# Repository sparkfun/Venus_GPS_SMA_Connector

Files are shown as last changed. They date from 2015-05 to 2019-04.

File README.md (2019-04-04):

**NOTE:** *This product has been retired from our catalog. If you are looking for more up-to-date info, please check out some of these resources to see how other users are still hacking and improving on this product.*
* *[SparkFun Forum](https://forum.sparkfun.com/)*
* *[Comments Here on GitHub](https://github.com/sparkfun/Venus_GPS_SMA_Connector/issues)*
* *[IRC Channel](https://www.sparkfun.com/news/263)*

SparkFun Venus GPS with SMA Connector
========================================

SparkFun Venus GPS with SMA Connector

[*SparkFun Venus GPS with SMA Connector (GPS-11058)*](https://www.sparkfun.com/products/11058)

This is the latest version of our Venus GPS board; the smallest, most powerful, and most versatile GPS receiver we carry. It’s based on the Venus638FLPx, the successor to the Venus634LPx. 
The Venus638FLPx outputs standard NMEA-0183 or SkyTraq Binary sentences at a default rate of 9600bps (adjustable to 115200bps), with update rates up to 20Hz! 
The Venus638FLPx also allows for limited on-chip logging (check out the firmware below), as well as external logging using a SPI flash memory chip (not included).

Repository Contents
-------------------

* **/Hardware** - Eagle design files (.brd, .sch)
* **/Production** - Production panel files (.brd)

Documentation
--------------

* **[SparkFun Fritzing repo](https://github.com/sparkfun/Fritzing_Parts)** - Fritzing diagrams for SparkFun products.
* **[SparkFun 3D Model repo](https://github.com/sparkfun/3D_Models)** - 3D models of SparkFun products. 

License Information
-------------------
This product is _**open source**_! 

The **hardware** is released under [Creative Commons ShareAlike 4.0 International](https://creativecommons.org/licenses/by-sa/4.0/).

Please use, reuse, and modify these files as you see fit. Please maintain attribution to SparkFun Electronics and release anything derivative under the same license.

Distributed as-is; no warranty is given.

- Your friends at SparkFun.

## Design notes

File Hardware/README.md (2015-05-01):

SparkFun <PRODUCT NAME> Design Files
=====================================

The .sch and .brd files hare are Eagle CAD schematic and PCB design files from SparkFun Electronics.
A freeware version of Eagle can be found [here](http://www.cadsoftusa.com/download-eagle/freeware/). 

License
---------
This product is open source! 
The hardware is released under [Creative Commons ShareAlike 4.0 International](https://creativecommons.org/licenses/by-sa/4.0/).

Please use, reuse, and modify these files as you see fit. Please maintain attribution to SparkFun Electronics and release anything derivative under the same license.

Distributed as-is; no warranty is given.

- Your friends at SparkFun.

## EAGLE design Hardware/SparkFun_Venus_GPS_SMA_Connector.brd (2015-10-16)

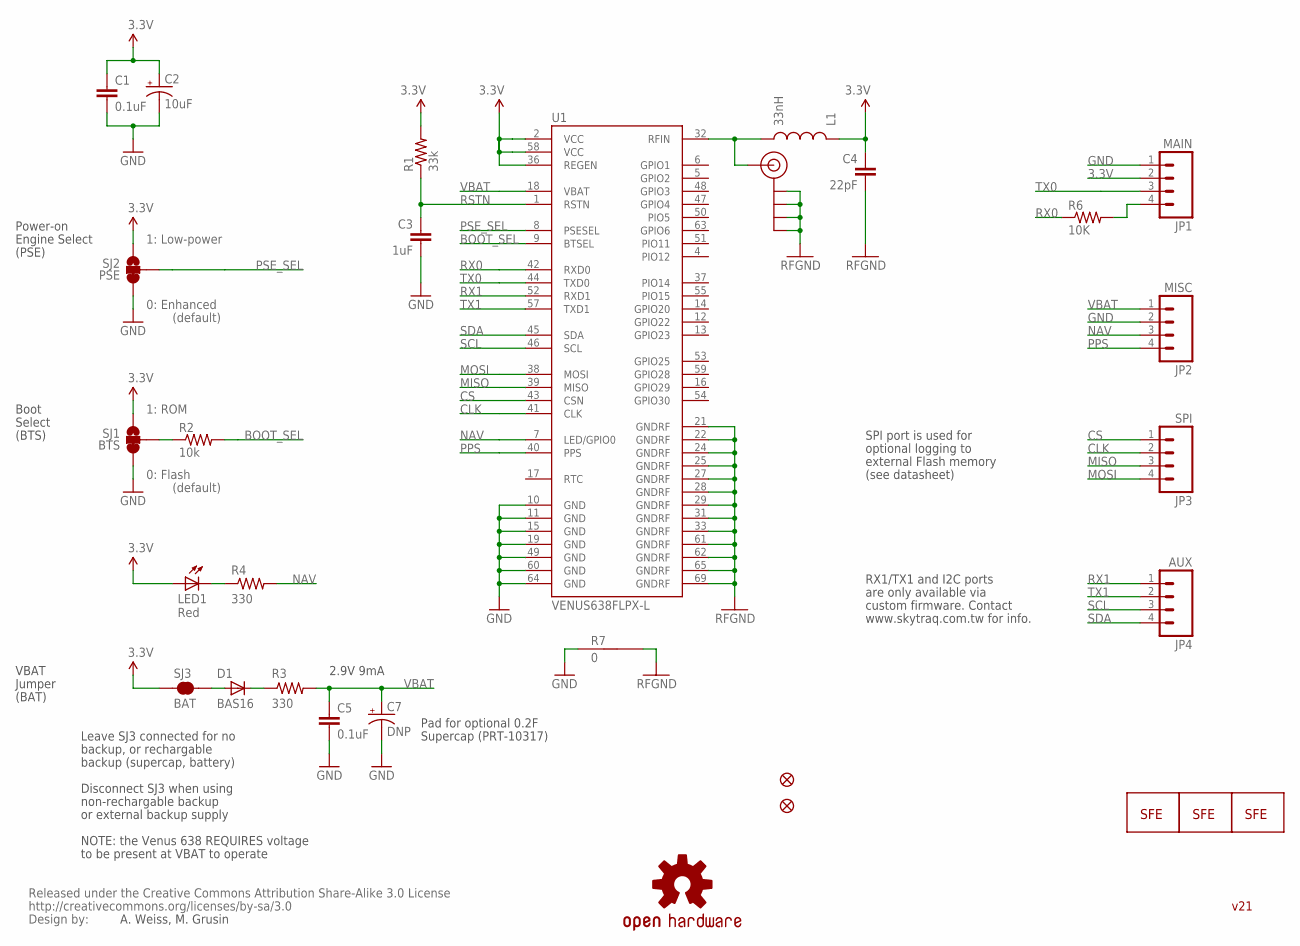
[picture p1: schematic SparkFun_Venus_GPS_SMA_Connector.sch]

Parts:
C1, C5: 0.1uF; 0402-CAP
C2: 10uF; EIA3216
C3: 1uF; 0402-CAP
C4: 22pF; 0402-CAP
C7: DNP; EN_J2
D1: BAS16; SOD-323
JP1: MAIN; 1X04
JP2: MISC; 1X04
JP3: SPI; 1X04
JP4: AUX; 1X04
JP5: SMA_EDGE; SMA-EDGE
JP6, JP7: FIDUCIALUFIDUCIAL; MICRO-FIDUCIAL
L1: 33nH; C0402
LED1: Red; LED-0603
LOGO1, LOGO2: LOGO-SFESK; SFE-LOGO-FLAME
LOGO3: LOGO-SFENW2; SFE-NEW-WEB
R1: 33k; 0402-RES
R2: 10k; 0402-RES
R3, R4: 330; 0402-RES
R6: 10K; 0402-RES
R7: 0; GND-JUMP
SJ1: BTS; SJ_3_PASTE2&3
SJ2: PSE; SJ_3_PASTE2&3
SJ3: BAT; SJ_2S
U1: VENUS638FLPX-L; VENUS638FLPX
U$4: OSHW-LOGOS; OSHW-LOGO-S
U$5: CREATIVE_COMMONS

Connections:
3.3V: C1.1, C2.A (+), C4.1, JP1.2, L1.1, LED1.A, R1.2, SJ1.1, SJ2.1, SJ3.1, U1.2 (VCC), U1.36 (REGEN), U1.58 (VCC)
ANT: JP5.SIG (SIGNAL), L1.2, U1.32 (RFIN)
BOOT_SEL: R2.2, U1.9 (BTSEL)
CLK: JP3.2, U1.41 (CLK)
CS: JP3.1, U1.43 (CSN)
GND: C1.2, C2.C (-), C3.2, C5.2, C7.-, JP1.1, JP2.2, R7.1, SJ1.3, SJ2.3, U1.10 (GND), U1.11 (GND), U1.15 (GND), U1.19 (GND), U1.49 (GND), U1.60 (GND), U1.64 (GND)
MISO: JP3.3, U1.39 (MISO)
MOSI: JP3.4, U1.38 (MOSI)
unnamed: LED1.C, R4.1
unnamed: R2.1, SJ1.2
unnamed: D1.1 (C), R3.1
unnamed: D1.2 (A), SJ3.2
NAV: JP2.3, R4.2, U1.7 (LED/GPIO0)
PPS: JP2.4, U1.40 (PPS)
PSE_SEL: SJ2.2, U1.8 (PSESEL)
RFGND: C4.2, JP5.GND@0 (GND), JP5.GND@1 (GND), JP5.GND@2 (GND), JP5.GND@3 (GND), R7.2, U1.21 (GNDRF), U1.22 (GNDRF), U1.24 (GNDRF), U1.25 (GNDRF), U1.27 (GNDRF), U1.28 (GNDRF), U1.29 (GNDRF), U1.31 (GNDRF), U1.33 (GNDRF), U1.61 (GNDRF), U1.62 (GNDRF), U1.65 (GNDRF), U1.69 (GNDRF)
RSTN: C3.1, R1.1, U1.1 (RSTN)
RX0: R6.1, U1.42 (RXD0)
RX1: JP4.1, U1.52 (RXD1)
RX01: JP1.4, R6.2
SCL: JP4.3, U1.46 (SCL)
SDA: JP4.4, U1.45 (SDA)
TX0: JP1.3, U1.44 (TXD0)
TX1: JP4.2, U1.57 (TXD1)
VBAT: C5.1, C7.+, JP2.1, R3.2, U1.18 (VBAT)

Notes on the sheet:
RFGND
1: Low-power
0: Enhanced
0: Flash
1: ROM
(default)
A. Weiss, M. Grusin
Supercap (PRT-10317)
Pad for optional 0.2F
2.9V 9mA
RX1/TX1 and I2C ports
are only available via
SPI port is used for
optional logging to
external Flash memory
(see datasheet)
custom firmware. Contact
www.skytraq.com.tw for info.
Power-on
Engine Select
Boot
Select
(PSE)
(BTS)
VBAT
Jumper
(BAT)
Leave SJ3 connected for no
backup, or rechargable
backup (supercap, battery)
Disconnect SJ3 when using
non-rechargable backup
or external backup supply
NOTE: the Venus 638 REQUIRES voltage
to be present at VBAT to operate
v21

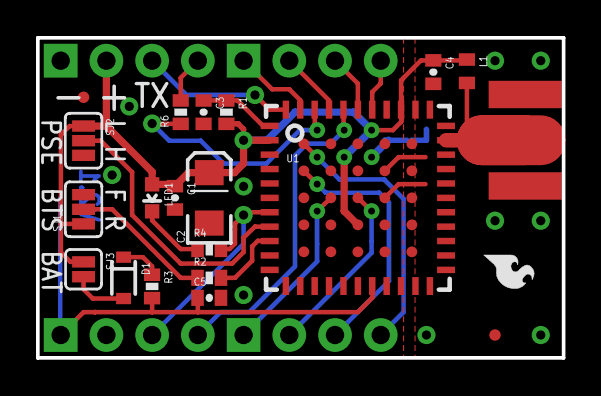
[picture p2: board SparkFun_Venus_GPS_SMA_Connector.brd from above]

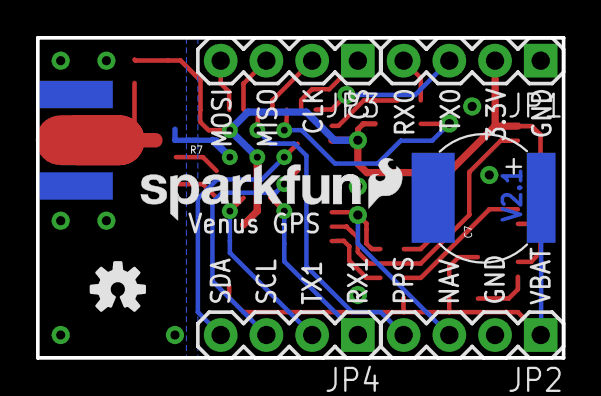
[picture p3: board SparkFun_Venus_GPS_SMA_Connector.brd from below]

Board: 2 copper layers, 29.2 x 17.8 mm, 31 parts (9 on the bottom side), 25 nets.

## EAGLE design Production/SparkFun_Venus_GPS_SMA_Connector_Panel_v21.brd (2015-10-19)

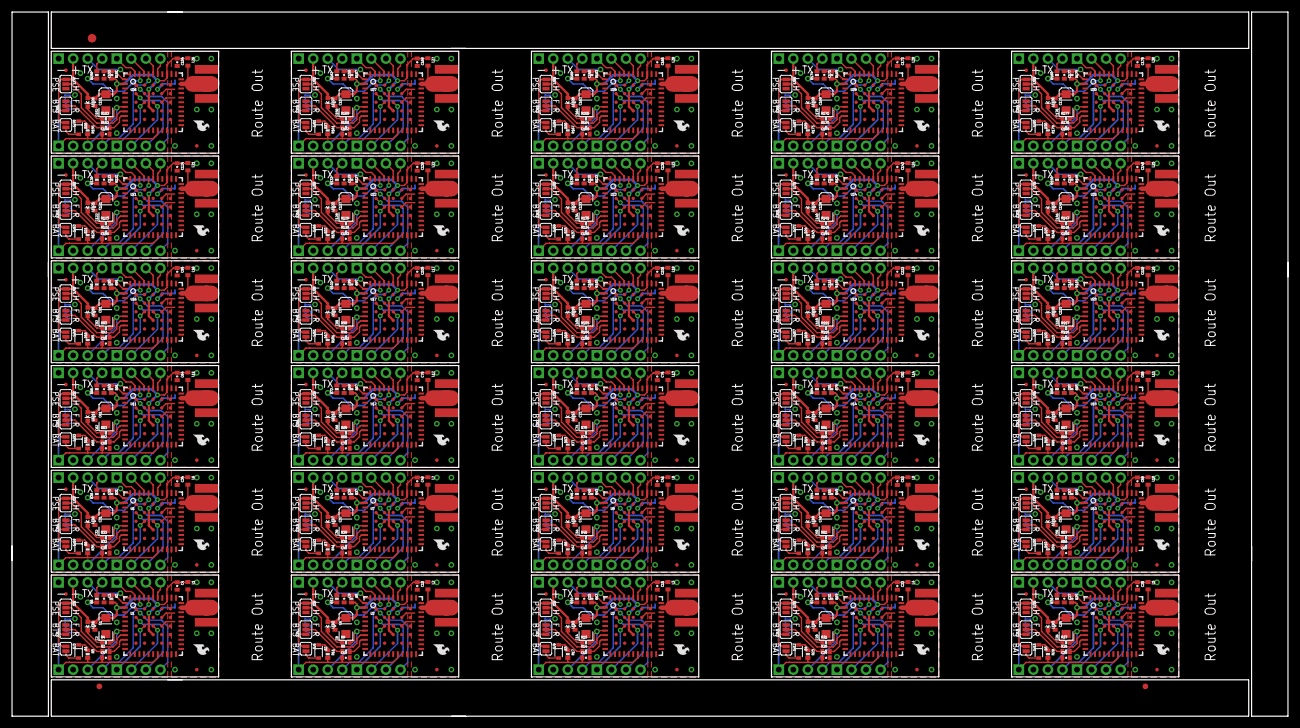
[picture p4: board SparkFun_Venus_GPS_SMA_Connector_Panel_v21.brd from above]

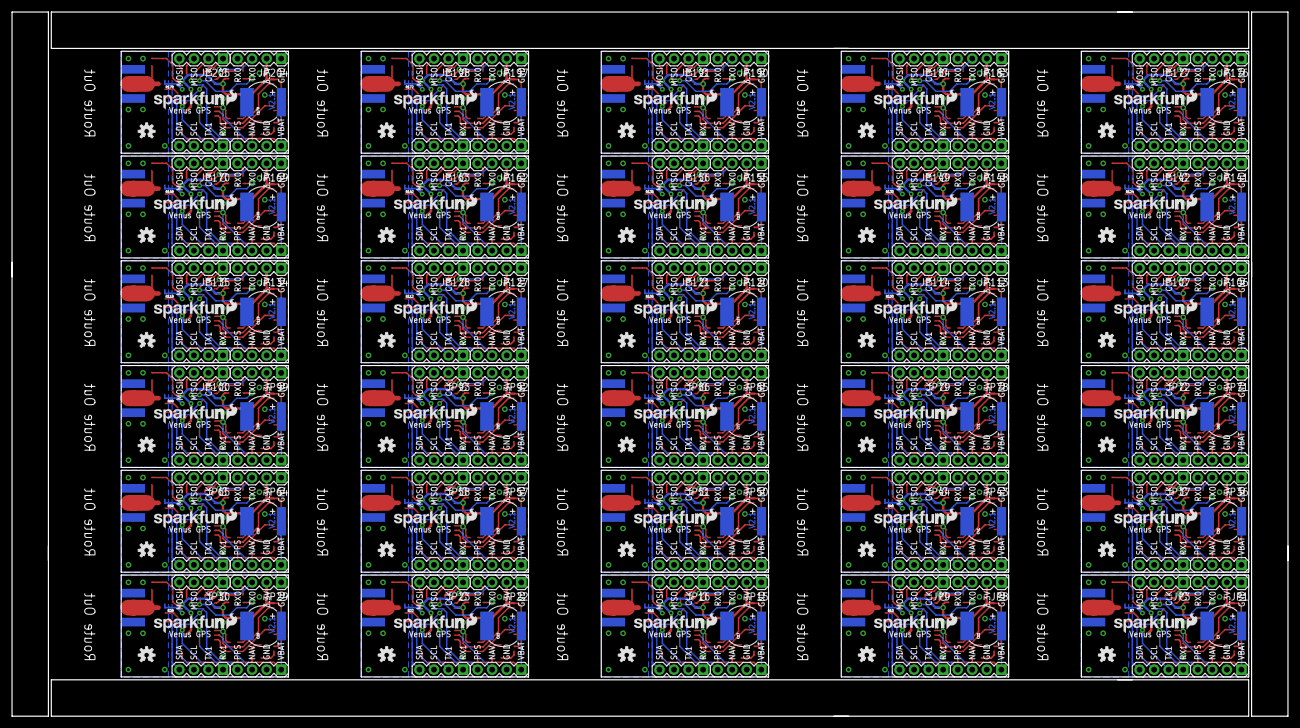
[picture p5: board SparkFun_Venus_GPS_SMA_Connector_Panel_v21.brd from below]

Board: 2 copper layers, 222.8 x 122.9 mm, 903 parts (270 on the bottom side), 750 nets.

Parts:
C1, C5, C6, C12, C13, C18, C19, C24, C25, C30, C31, C36, C37, C42, C43, C48, C49, C54, C55, C60, C61, C66, C67, C72, C73, C78, C79, C84, C85, C90, C91, C96, C97, C102, C103, C108, C109, C114, C115, C120, C121, C126, C127, C132, C133, C138, C139, C144, C145, C150, C151, C156, C157, C162, C163, C168, C169, C174, C175, C180: 0.1uF; 0402-CAP
C2, C8, C14, C20, C26, C32, C38, C44, C50, C56, C62, C68, C74, C80, C86, C92, C98, C104, C110, C116, C122, C128, C134, C140, C146, C152, C158, C164, C170, C176: 10uF; EIA3216
C3, C9, C15, C21, C27, C33, C39, C45, C51, C57, C63, C69, C75, C81, C87, C93, C99, C105, C111, C117, C123, C129, C135, C141, C147, C153, C159, C165, C171, C177: 1uF; 0402-CAP
C4, C10, C16, C22, C28, C34, C40, C46, C52, C58, C64, C70, C76, C82, C88, C94, C100, C106, C112, C118, C124, C130, C136, C142, C148, C154, C160, C166, C172, C178: 22pF; 0402-CAP
C7, C11, C17, C23, C29, C35, C41, C47, C53, C59, C65, C71, C77, C83, C89, C95, C101, C107, C113, C119, C125, C131, C137, C143, C149, C155, C161, C167, C173, C179: DNP; EN_J2
D1, D2, D3, D4, D5, D6, D7, D8, D9, D10, D11, D12, D13, D14, D15, D16, D17, D18, D19, D20, D21, D22, D23, D24, D25, D26, D27, D28, D29, D30: BAS16; SOD-323
E$1: FIDUCIAL-1.5X3
E$3, E$4: FIDUCIAL-1X2
JP1, JP8, JP15, JP22, JP29, JP36, JP43, JP50, JP57, JP64, JP71, JP78, JP85, JP92, JP99, JP106, JP113, JP120, JP127, JP134, JP141, JP148, JP155, JP162, JP169, JP176, JP183, JP190, JP197, JP204: MAIN; 1X04
JP2, JP12, JP19, JP26, JP33, JP40, JP47, JP54, JP61, JP68, JP75, JP82, JP89, JP96, JP103, JP110, JP117, JP124, JP131, JP138, JP145, JP152, JP159, JP166, JP173, JP180, JP187, JP194, JP201, JP208: MISC; 1X04
JP3, JP9, JP16, JP23, JP30, JP37, JP44, JP51, JP58, JP65, JP72, JP79, JP86, JP93, JP100, JP107, JP114, JP121, JP128, JP135, JP142, JP149, JP156, JP163, JP170, JP177, JP184, JP191, JP198, JP205: SPI; 1X04
JP4, JP11, JP18, JP25, JP32, JP39, JP46, JP53, JP60, JP67, JP74, JP81, JP88, JP95, JP102, JP109, JP116, JP123, JP130, JP137, JP144, JP151, JP158, JP165, JP172, JP179, JP186, JP193, JP200, JP207: AUX; 1X04
JP5, JP10, JP17, JP24, JP31, JP38, JP45, JP52, JP59, JP66, JP73, JP80, JP87, JP94, JP101, JP108, JP115, JP122, JP129, JP136, JP143, JP150, JP157, JP164, JP171, JP178, JP185, JP192, JP199, JP206: SMA_EDGE; SMA-EDGE
JP6, JP7, JP13, JP14, JP20, JP21, JP27, JP28, JP34, JP35, JP41, JP42, JP48, JP49, JP55, JP56, JP62, JP63, JP69, JP70, JP76, JP77, JP83, JP84, JP90, JP91, JP97, JP98, JP104, JP105, JP111, JP112, JP118, JP119, JP125, JP126, JP132, JP133, JP139, JP140, JP146, JP147, JP153, JP154, JP160, JP161, JP167, JP168, JP174, JP175, JP181, JP182, JP188, JP189, JP195, JP196, JP202, JP203, JP209, JP210: FIDUCIALUFIDUCIAL; MICRO-FIDUCIAL
L1, L2, L3, L4, L5, L6, L7, L8, L9, L10, L11, L12, L13, L14, L15, L16, L17, L18, L19, L20, L21, L22, L23, L24, L25, L26, L27, L28, L29, L30: 33nH; C0402
LED1, LED2, LED3, LED4, LED5, LED6, LED7, LED8, LED9, LED10, LED11, LED12, LED13, LED14, LED15, LED16, LED17, LED18, LED19, LED20, LED21, LED22, LED23, LED24, LED25, LED26, LED27, LED28, LED29, LED30: Red; LED-0603
LOGO1, LOGO2, LOGO4, LOGO6, LOGO7, LOGO9, LOGO10, LOGO12, LOGO13, LOGO15, LOGO16, LOGO18, LOGO19, LOGO21, LOGO22, LOGO24, LOGO25, LOGO27, LOGO28, LOGO30, LOGO31, LOGO33, LOGO34, LOGO36, LOGO37, LOGO39, LOGO40, LOGO42, LOGO43, LOGO45, LOGO46, LOGO48, LOGO49, LOGO51, LOGO52, LOGO54, LOGO55, LOGO57, LOGO58, LOGO60, LOGO61, LOGO63, LOGO64, LOGO66, LOGO67, LOGO69, LOGO70, LOGO72, LOGO73, LOGO75, LOGO76, LOGO78, LOGO79, LOGO81, LOGO82, LOGO84, LOGO85, LOGO87, LOGO88, LOGO90: LOGO-SFESK; SFE-LOGO-FLAME
LOGO3, LOGO5, LOGO8, LOGO11, LOGO14, LOGO17, LOGO20, LOGO23, LOGO26, LOGO29, LOGO32, LOGO35, LOGO38, LOGO41, LOGO44, LOGO47, LOGO50, LOGO53, LOGO56, LOGO59, LOGO62, LOGO65, LOGO68, LOGO71, LOGO74, LOGO77, LOGO80, LOGO83, LOGO86, LOGO89: LOGO-SFENW2; SFE-NEW-WEB
R1, R5, R13, R19, R25, R31, R37, R43, R49, R55, R61, R67, R73, R79, R85, R91, R97, R103, R109, R115, R121, R127, R133, R139, R145, R151, R157, R163, R169, R175: 33k; 0402-RES
R2, R8, R14, R20, R26, R32, R38, R44, R50, R56, R62, R68, R74, R80, R86, R92, R98, R104, R110, R116, R122, R128, R134, R140, R146, R152, R158, R164, R170, R176: 10k; 0402-RES
R3, R4, R9, R11, R15, R17, R21, R23, R27, R29, R33, R35, R39, R41, R45, R47, R51, R53, R57, R59, R63, R65, R69, R71, R75, R77, R81, R83, R87, R89, R93, R95, R99, R101, R105, R107, R111, R113, R117, R119, R123, R125, R129, R131, R135, R137, R141, R143, R147, R149, R153, R155, R159, R161, R165, R167, R171, R173, R177, R179: 330; 0402-RES
R6, R12, R18, R24, R30, R36, R42, R48, R54, R60, R66, R72, R78, R84, R90, R96, R102, R108, R114, R120, R126, R132, R138, R144, R150, R156, R162, R168, R174, R180: 10K; 0402-RES
R7, R10, R16, R22, R28, R34, R40, R46, R52, R58, R64, R70, R76, R82, R88, R94, R100, R106, R112, R118, R124, R130, R136, R142, R148, R154, R160, R166, R172, R178: 0; GND-JUMP
SJ1, SJ4, SJ7, SJ10, SJ13, SJ16, SJ19, SJ22, SJ25, SJ28, SJ31, SJ34, SJ37, SJ40, SJ43, SJ46, SJ49, SJ52, SJ55, SJ58, SJ61, SJ64, SJ67, SJ70, SJ73, SJ76, SJ79, SJ82, SJ85, SJ88: BTS; SJ_3_PASTE2&3
SJ2, SJ5, SJ8, SJ11, SJ14, SJ17, SJ20, SJ23, SJ26, SJ29, SJ32, SJ35, SJ38, SJ41, SJ44, SJ47, SJ50, SJ53, SJ56, SJ59, SJ62, SJ65, SJ68, SJ71, SJ74, SJ77, SJ80, SJ83, SJ86, SJ89: PSE; SJ_3_PASTE2&3
SJ3, SJ6, SJ9, SJ12, SJ15, SJ18, SJ21, SJ24, SJ27, SJ30, SJ33, SJ36, SJ39, SJ42, SJ45, SJ48, SJ51, SJ54, SJ57, SJ60, SJ63, SJ66, SJ69, SJ72, SJ75, SJ78, SJ81, SJ84, SJ87, SJ90: BAT; SJ_2S
U1, U2, U3, U4, U5, U6, U7, U8, U9, U10, U11, U12, U13, U14, U15, U16, U17, U18, U19, U20, U21, U22, U23, U24, U25, U26, U27, U28, U29, U30: VENUS638FLPX-L; VENUS638FLPX
U$1, U$2, U$3, U$4, U$5, U$6, U$7, U$8, U$9, U$10, U$11, U$12, U$13, U$14, U$15, U$16, U$17, U$18, U$19, U$20, U$21, U$22, U$23, U$24, U$25, U$26, U$27, U$28, U$29, U$30: OSHW-LOGOS; OSHW-LOGO-S

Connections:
3.3V: C1.1, C2.A, C4.1, JP1.2, L1.1, LED1.A, R1.2, SJ1.1, SJ2.1, SJ3.1, U1.2, U1.36, U1.58
3.3V1: C6.1, C8.A, C10.1, JP8.2, L2.1, LED2.A, R5.2, SJ4.1, SJ5.1, SJ6.1, U2.2, U2.36, U2.58
3.3V2: C13.1, C14.A, C16.1, JP15.2, L3.1, LED3.A, R13.2, SJ7.1, SJ8.1, SJ9.1, U3.2, U3.36, U3.58
3.3V3: C19.1, C20.A, C22.1, JP22.2, L4.1, LED4.A, R19.2, SJ10.1, SJ11.1, SJ12.1, U4.2, U4.36, U4.58
3.3V4: C25.1, C26.A, C28.1, JP29.2, L5.1, LED5.A, R25.2, SJ13.1, SJ14.1, SJ15.1, U5.2, U5.36, U5.58
3.3V5: C31.1, C32.A, C34.1, JP36.2, L6.1, LED6.A, R31.2, SJ16.1, SJ17.1, SJ18.1, U6.2, U6.36, U6.58
3.3V6: C37.1, C38.A, C40.1, JP43.2, L7.1, LED7.A, R37.2, SJ19.1, SJ20.1, SJ21.1, U7.2, U7.36, U7.58
3.3V7: C43.1, C44.A, C46.1, JP50.2, L8.1, LED8.A, R43.2, SJ22.1, SJ23.1, SJ24.1, U8.2, U8.36, U8.58
3.3V8: C49.1, C50.A, C52.1, JP57.2, L9.1, LED9.A, R49.2, SJ25.1, SJ26.1, SJ27.1, U9.2, U9.36, U9.58
3.3V9: C55.1, C56.A, C58.1, JP64.2, L10.1, LED10.A, R55.2, SJ28.1, SJ29.1, SJ30.1, U10.2, U10.36, U10.58
3.3V10: C61.1, C62.A, C64.1, JP71.2, L11.1, LED11.A, R61.2, SJ31.1, SJ32.1, SJ33.1, U11.2, U11.36, U11.58
3.3V11: C67.1, C68.A, C70.1, JP78.2, L12.1, LED12.A, R67.2, SJ34.1, SJ35.1, SJ36.1, U12.2, U12.36, U12.58
3.3V12: C73.1, C74.A, C76.1, JP85.2, L13.1, LED13.A, R73.2, SJ37.1, SJ38.1, SJ39.1, U13.2, U13.36, U13.58
3.3V13: C79.1, C80.A, C82.1, JP92.2, L14.1, LED14.A, R79.2, SJ40.1, SJ41.1, SJ42.1, U14.2, U14.36, U14.58
3.3V14: C85.1, C86.A, C88.1, JP99.2, L15.1, LED15.A, R85.2, SJ43.1, SJ44.1, SJ45.1, U15.2, U15.36, U15.58
3.3V15: C91.1, C92.A, C94.1, JP106.2, L16.1, LED16.A, R91.2, SJ46.1, SJ47.1, SJ48.1, U16.2, U16.36, U16.58
3.3V16: C97.1, C98.A, C100.1, JP113.2, L17.1, LED17.A, R97.2, SJ49.1, SJ50.1, SJ51.1, U17.2, U17.36, U17.58
3.3V17: C103.1, C104.A, C106.1, JP120.2, L18.1, LED18.A, R103.2, SJ52.1, SJ53.1, SJ54.1, U18.2, U18.36, U18.58
3.3V18: C109.1, C110.A, C112.1, JP127.2, L19.1, LED19.A, R109.2, SJ55.1, SJ56.1, SJ57.1, U19.2, U19.36, U19.58
3.3V19: C115.1, C116.A, C118.1, JP134.2, L20.1, LED20.A, R115.2, SJ58.1, SJ59.1, SJ60.1, U20.2, U20.36, U20.58
3.3V20: C121.1, C122.A, C124.1, JP141.2, L21.1, LED21.A, R121.2, SJ61.1, SJ62.1, SJ63.1, U21.2, U21.36, U21.58
3.3V21: C127.1, C128.A, C130.1, JP148.2, L22.1, LED22.A, R127.2, SJ64.1, SJ65.1, SJ66.1, U22.2, U22.36, U22.58
3.3V22: C133.1, C134.A, C136.1, JP155.2, L23.1, LED23.A, R133.2, SJ67.1, SJ68.1, SJ69.1, U23.2, U23.36, U23.58
3.3V23: C139.1, C140.A, C142.1, JP162.2, L24.1, LED24.A, R139.2, SJ70.1, SJ71.1, SJ72.1, U24.2, U24.36, U24.58
3.3V24: C145.1, C146.A, C148.1, JP169.2, L25.1, LED25.A, R145.2, SJ73.1, SJ74.1, SJ75.1, U25.2, U25.36, U25.58
3.3V25: C151.1, C152.A, C154.1, JP176.2, L26.1, LED26.A, R151.2, SJ76.1, SJ77.1, SJ78.1, U26.2, U26.36, U26.58
3.3V26: C157.1, C158.A, C160.1, JP183.2, L27.1, LED27.A, R157.2, SJ79.1, SJ80.1, SJ81.1, U27.2, U27.36, U27.58
3.3V27: C163.1, C164.A, C166.1, JP190.2, L28.1, LED28.A, R163.2, SJ82.1, SJ83.1, SJ84.1, U28.2, U28.36, U28.58
3.3V28: C169.1, C170.A, C172.1, JP197.2, L29.1, LED29.A, R169.2, SJ85.1, SJ86.1, SJ87.1, U29.2, U29.36, U29.58
3.3V29: C175.1, C176.A, C178.1, JP204.2, L30.1, LED30.A, R175.2, SJ88.1, SJ89.1, SJ90.1, U30.2, U30.36, U30.58
ANT: JP5.SIG, L1.2, U1.32
ANT1: JP10.SIG, L2.2, U2.32
ANT2: JP17.SIG, L3.2, U3.32
ANT3: JP24.SIG, L4.2, U4.32
ANT4: JP31.SIG, L5.2, U5.32
ANT5: JP38.SIG, L6.2, U6.32
ANT6: JP45.SIG, L7.2, U7.32
ANT7: JP52.SIG, L8.2, U8.32
ANT8: JP59.SIG, L9.2, U9.32
ANT9: JP66.SIG, L10.2, U10.32
ANT10: JP73.SIG, L11.2, U11.32
ANT11: JP80.SIG, L12.2, U12.32
ANT12: JP87.SIG, L13.2, U13.32
ANT13: JP94.SIG, L14.2, U14.32
ANT14: JP101.SIG, L15.2, U15.32
ANT15: JP108.SIG, L16.2, U16.32
ANT16: JP115.SIG, L17.2, U17.32
ANT17: JP122.SIG, L18.2, U18.32
ANT18: JP129.SIG, L19.2, U19.32
ANT19: JP136.SIG, L20.2, U20.32
ANT20: JP143.SIG, L21.2, U21.32
ANT21: JP150.SIG, L22.2, U22.32
ANT22: JP157.SIG, L23.2, U23.32
ANT23: JP164.SIG, L24.2, U24.32
ANT24: JP171.SIG, L25.2, U25.32
ANT25: JP178.SIG, L26.2, U26.32
ANT26: JP185.SIG, L27.2, U27.32
ANT27: JP192.SIG, L28.2, U28.32
ANT28: JP199.SIG, L29.2, U29.32
ANT29: JP206.SIG, L30.2, U30.32
BOOT_SEL: R2.2, U1.9
BOOT_SEL1: R8.2, U2.9
BOOT_SEL2: R14.2, U3.9
BOOT_SEL3: R20.2, U4.9
BOOT_SEL4: R26.2, U5.9
BOOT_SEL5: R32.2, U6.9
BOOT_SEL6: R38.2, U7.9
BOOT_SEL7: R44.2, U8.9
BOOT_SEL8: R50.2, U9.9
BOOT_SEL9: R56.2, U10.9
BOOT_SEL10: R62.2, U11.9
BOOT_SEL11: R68.2, U12.9
BOOT_SEL12: R74.2, U13.9
BOOT_SEL13: R80.2, U14.9
BOOT_SEL14: R86.2, U15.9
BOOT_SEL15: R92.2, U16.9
BOOT_SEL16: R98.2, U17.9
BOOT_SEL17: R104.2, U18.9
BOOT_SEL18: R110.2, U19.9
BOOT_SEL19: R116.2, U20.9
BOOT_SEL20: R122.2, U21.9
BOOT_SEL21: R128.2, U22.9
BOOT_SEL22: R134.2, U23.9
BOOT_SEL23: R140.2, U24.9
BOOT_SEL24: R146.2, U25.9
BOOT_SEL25: R152.2, U26.9
BOOT_SEL26: R158.2, U27.9
BOOT_SEL27: R164.2, U28.9
BOOT_SEL28: R170.2, U29.9
BOOT_SEL29: R176.2, U30.9
CLK: JP3.2, U1.41
CLK1: JP9.2, U2.41
CLK2: JP16.2, U3.41
CLK3: JP23.2, U4.41
CLK4: JP30.2, U5.41
CLK5: JP37.2, U6.41
CLK6: JP44.2, U7.41
CLK7: JP51.2, U8.41
CLK8: JP58.2, U9.41
CLK9: JP65.2, U10.41
CLK10: JP72.2, U11.41
CLK11: JP79.2, U12.41
CLK12: JP86.2, U13.41
CLK13: JP93.2, U14.41
CLK14: JP100.2, U15.41
CLK15: JP107.2, U16.41
CLK16: JP114.2, U17.41
CLK17: JP121.2, U18.41
CLK18: JP128.2, U19.41
CLK19: JP135.2, U20.41
CLK20: JP142.2, U21.41
CLK21: JP149.2, U22.41
CLK22: JP156.2, U23.41
CLK23: JP163.2, U24.41
CLK24: JP170.2, U25.41
CLK25: JP177.2, U26.41
CLK26: JP184.2, U27.41
CLK27: JP191.2, U28.41
CLK28: JP198.2, U29.41
CLK29: JP205.2, U30.41
CS: JP3.1, U1.43
CS1: JP9.1, U2.43
CS2: JP16.1, U3.43
CS3: JP23.1, U4.43
CS4: JP30.1, U5.43
CS5: JP37.1, U6.43
CS6: JP44.1, U7.43
CS7: JP51.1, U8.43
CS8: JP58.1, U9.43
CS9: JP65.1, U10.43
CS10: JP72.1, U11.43
CS11: JP79.1, U12.43
CS12: JP86.1, U13.43
CS13: JP93.1, U14.43
CS14: JP100.1, U15.43
CS15: JP107.1, U16.43
CS16: JP114.1, U17.43
CS17: JP121.1, U18.43
CS18: JP128.1, U19.43
CS19: JP135.1, U20.43
CS20: JP142.1, U21.43
CS21: JP149.1, U22.43
CS22: JP156.1, U23.43
CS23: JP163.1, U24.43
CS24: JP170.1, U25.43
CS25: JP177.1, U26.43
CS26: JP184.1, U27.43
CS27: JP191.1, U28.43
CS28: JP198.1, U29.43
CS29: JP205.1, U30.43
GND: C1.2, C2.C, C3.2, C5.2, C7.-, JP1.1, JP2.2, R7.1, SJ1.3, SJ2.3, U1.10, U1.11, U1.15, U1.19, U1.49, U1.60, U1.64
GND1: C6.2, C8.C, C9.2, C11.-, C12.2, JP8.1, JP12.2, R10.1, SJ4.3, SJ5.3, U2.10, U2.11, U2.15, U2.19, U2.49, U2.60, U2.64
GND2: C13.2, C14.C, C15.2, C17.-, C18.2, JP15.1, JP19.2, R16.1, SJ7.3, SJ8.3, U3.10, U3.11, U3.15, U3.19, U3.49, U3.60, U3.64
GND3: C19.2, C20.C, C21.2, C23.-, C24.2, JP22.1, JP26.2, R22.1, SJ10.3, SJ11.3, U4.10, U4.11, U4.15, U4.19, U4.49, U4.60, U4.64
GND4: C25.2, C26.C, C27.2, C29.-, C30.2, JP29.1, JP33.2, R28.1, SJ13.3, SJ14.3, U5.10, U5.11, U5.15, U5.19, U5.49, U5.60, U5.64
GND5: C31.2, C32.C, C33.2, C35.-, C36.2, JP36.1, JP40.2, R34.1, SJ16.3, SJ17.3, U6.10, U6.11, U6.15, U6.19, U6.49, U6.60, U6.64
GND6: C37.2, C38.C, C39.2, C41.-, C42.2, JP43.1, JP47.2, R40.1, SJ19.3, SJ20.3, U7.10, U7.11, U7.15, U7.19, U7.49, U7.60, U7.64
GND7: C43.2, C44.C, C45.2, C47.-, C48.2, JP50.1, JP54.2, R46.1, SJ22.3, SJ23.3, U8.10, U8.11, U8.15, U8.19, U8.49, U8.60, U8.64
GND8: C49.2, C50.C, C51.2, C53.-, C54.2, JP57.1, JP61.2, R52.1, SJ25.3, SJ26.3, U9.10, U9.11, U9.15, U9.19, U9.49, U9.60, U9.64
GND9: C55.2, C56.C, C57.2, C59.-, C60.2, JP64.1, JP68.2, R58.1, SJ28.3, SJ29.3, U10.10, U10.11, U10.15, U10.19, U10.49, U10.60, U10.64
GND10: C61.2, C62.C, C63.2, C65.-, C66.2, JP71.1, JP75.2, R64.1, SJ31.3, SJ32.3, U11.10, U11.11, U11.15, U11.19, U11.49, U11.60, U11.64
GND11: C67.2, C68.C, C69.2, C71.-, C72.2, JP78.1, JP82.2, R70.1, SJ34.3, SJ35.3, U12.10, U12.11, U12.15, U12.19, U12.49, U12.60, U12.64
GND12: C73.2, C74.C, C75.2, C77.-, C78.2, JP85.1, JP89.2, R76.1, SJ37.3, SJ38.3, U13.10, U13.11, U13.15, U13.19, U13.49, U13.60, U13.64
GND13: C79.2, C80.C, C81.2, C83.-, C84.2, JP92.1, JP96.2, R82.1, SJ40.3, SJ41.3, U14.10, U14.11, U14.15, U14.19, U14.49, U14.60, U14.64
GND14: C85.2, C86.C, C87.2, C89.-, C90.2, JP99.1, JP103.2, R88.1, SJ43.3, SJ44.3, U15.10, U15.11, U15.15, U15.19, U15.49, U15.60, U15.64
GND15: C91.2, C92.C, C93.2, C95.-, C96.2, JP106.1, JP110.2, R94.1, SJ46.3, SJ47.3, U16.10, U16.11, U16.15, U16.19, U16.49, U16.60, U16.64
GND16: C97.2, C98.C, C99.2, C101.-, C102.2, JP113.1, JP117.2, R100.1, SJ49.3, SJ50.3, U17.10, U17.11, U17.15, U17.19, U17.49, U17.60, U17.64
GND17: C103.2, C104.C, C105.2, C107.-, C108.2, JP120.1, JP124.2, R106.1, SJ52.3, SJ53.3, U18.10, U18.11, U18.15, U18.19, U18.49, U18.60, U18.64
GND18: C109.2, C110.C, C111.2, C113.-, C114.2, JP127.1, JP131.2, R112.1, SJ55.3, SJ56.3, U19.10, U19.11, U19.15, U19.19, U19.49, U19.60, U19.64
GND19: C115.2, C116.C, C117.2, C119.-, C120.2, JP134.1, JP138.2, R118.1, SJ58.3, SJ59.3, U20.10, U20.11, U20.15, U20.19, U20.49, U20.60, U20.64
GND20: C121.2, C122.C, C123.2, C125.-, C126.2, JP141.1, JP145.2, R124.1, SJ61.3, SJ62.3, U21.10, U21.11, U21.15, U21.19, U21.49, U21.60, U21.64
GND21: C127.2, C128.C, C129.2, C131.-, C132.2, JP148.1, JP152.2, R130.1, SJ64.3, SJ65.3, U22.10, U22.11, U22.15, U22.19, U22.49, U22.60, U22.64
GND22: C133.2, C134.C, C135.2, C137.-, C138.2, JP155.1, JP159.2, R136.1, SJ67.3, SJ68.3, U23.10, U23.11, U23.15, U23.19, U23.49, U23.60, U23.64
GND23: C139.2, C140.C, C141.2, C143.-, C144.2, JP162.1, JP166.2, R142.1, SJ70.3, SJ71.3, U24.10, U24.11, U24.15, U24.19, U24.49, U24.60, U24.64
GND24: C145.2, C146.C, C147.2, C149.-, C150.2, JP169.1, JP173.2, R148.1, SJ73.3, SJ74.3, U25.10, U25.11, U25.15, U25.19, U25.49, U25.60, U25.64
GND25: C151.2, C152.C, C153.2, C155.-, C156.2, JP176.1, JP180.2, R154.1, SJ76.3, SJ77.3, U26.10, U26.11, U26.15, U26.19, U26.49, U26.60, U26.64
GND26: C157.2, C158.C, C159.2, C161.-, C162.2, JP183.1, JP187.2, R160.1, SJ79.3, SJ80.3, U27.10, U27.11, U27.15, U27.19, U27.49, U27.60, U27.64
GND27: C163.2, C164.C, C165.2, C167.-, C168.2, JP190.1, JP194.2, R166.1, SJ82.3, SJ83.3, U28.10, U28.11, U28.15, U28.19, U28.49, U28.60, U28.64
GND28: C169.2, C170.C, C171.2, C173.-, C174.2, JP197.1, JP201.2, R172.1, SJ85.3, SJ86.3, U29.10, U29.11, U29.15, U29.19, U29.49, U29.60, U29.64
GND29: C175.2, C176.C, C177.2, C179.-, C180.2, JP204.1, JP208.2, R178.1, SJ88.3, SJ89.3, U30.10, U30.11, U30.15, U30.19, U30.49, U30.60, U30.64
MISO: JP3.3, U1.39
MISO1: JP9.3, U2.39
MISO2: JP16.3, U3.39
MISO3: JP23.3, U4.39
MISO4: JP30.3, U5.39
MISO5: JP37.3, U6.39
MISO6: JP44.3, U7.39
MISO7: JP51.3, U8.39
MISO8: JP58.3, U9.39
MISO9: JP65.3, U10.39
MISO10: JP72.3, U11.39
MISO11: JP79.3, U12.39
MISO12: JP86.3, U13.39
MISO13: JP93.3, U14.39
MISO14: JP100.3, U15.39
MISO15: JP107.3, U16.39
MISO16: JP114.3, U17.39
MISO17: JP121.3, U18.39
MISO18: JP128.3, U19.39
MISO19: JP135.3, U20.39
MISO20: JP142.3, U21.39
MISO21: JP149.3, U22.39
MISO22: JP156.3, U23.39
MISO23: JP163.3, U24.39
MISO24: JP170.3, U25.39
MISO25: JP177.3, U26.39
MISO26: JP184.3, U27.39
MISO27: JP191.3, U28.39
MISO28: JP198.3, U29.39
MISO29: JP205.3, U30.39
MOSI: JP3.4, U1.38
MOSI1: JP9.4, U2.38
MOSI2: JP16.4, U3.38
MOSI3: JP23.4, U4.38
MOSI4: JP30.4, U5.38
MOSI5: JP37.4, U6.38
MOSI6: JP44.4, U7.38
MOSI7: JP51.4, U8.38
MOSI8: JP58.4, U9.38
MOSI9: JP65.4, U10.38
MOSI10: JP72.4, U11.38
MOSI11: JP79.4, U12.38
MOSI12: JP86.4, U13.38
MOSI13: JP93.4, U14.38
MOSI14: JP100.4, U15.38
MOSI15: JP107.4, U16.38
MOSI16: JP114.4, U17.38
MOSI17: JP121.4, U18.38
MOSI18: JP128.4, U19.38
MOSI19: JP135.4, U20.38
MOSI20: JP142.4, U21.38
MOSI21: JP149.4, U22.38
MOSI22: JP156.4, U23.38
MOSI23: JP163.4, U24.38
MOSI24: JP170.4, U25.38
MOSI25: JP177.4, U26.38
MOSI26: JP184.4, U27.38
MOSI27: JP191.4, U28.38
MOSI28: JP198.4, U29.38
MOSI29: JP205.4, U30.38
unnamed: LED1.C, R4.1
unnamed: R2.1, SJ1.2
unnamed: D1.1, R3.1
unnamed: LED2.C, R9.1
unnamed: R8.1, SJ4.2
unnamed: D1.2, SJ3.2
unnamed: D2.2, SJ6.2
unnamed: D2.1, R11.1
unnamed: LED3.C, R15.1
unnamed: R14.1, SJ7.2
unnamed: D3.2, SJ9.2
unnamed: D3.1, R17.1
unnamed: LED4.C, R21.1
unnamed: R20.1, SJ10.2
unnamed: D4.2, SJ12.2
unnamed: D4.1, R23.1
unnamed: LED5.C, R27.1
unnamed: R26.1, SJ13.2
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

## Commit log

2015-05-01 Adding hardware files, updating README
    [SparkFun_Venus_GPS_SMA_Connector.brd, SparkFun_Venus_GPS_SMA_Connector.sch]
2015-10-16 Updated PWR-RF GND jumper to fix Eagle issue
    The Venus has power and rf grounds that should only connect at one place
    on the board (R7). There was an issue with Eagle not automatically
    connecting to this ground, leaving airwires. Part updated and overt
    traces added.
    [SparkFun_Venus_GPS_SMA_Connector.brd, SparkFun_Venus_GPS_SMA_Connector.sch]
2015-10-19 created new panel v21
    [SparkFun_Venus_GPS_SMA_Connector_Panel_v21.brd]

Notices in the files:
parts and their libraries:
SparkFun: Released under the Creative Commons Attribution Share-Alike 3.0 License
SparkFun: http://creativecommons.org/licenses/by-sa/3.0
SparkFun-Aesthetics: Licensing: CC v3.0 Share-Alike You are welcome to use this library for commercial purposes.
